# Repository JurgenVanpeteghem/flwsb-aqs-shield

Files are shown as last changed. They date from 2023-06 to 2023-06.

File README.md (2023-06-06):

# Air quality sensor shield
Flexible LoRaWAN Sensor Board - Air quality sensors shield

# Schematic
The schematic for the sensor shield was made using the reference schematics from the datasheets of the sensors. By adding female headers we can connect the main board to the sensorboard by using a male-female shield system. 
Four mounting holes were added to mount the board in an enclosure.

Connectorboard Figuur 1: Connectorboard

# PCB
For the project we made a seperate sensorboard wich contains all the sensors we used for the project. The purpose of this connector board is to connect all sensors to the main FLWSB. The FLWSB can collect the data drom the sensors on this board and send this data over lorawan.

The board contains following sensors to measure differnent parameters of airquality: 
  - BME280 (relative humidity and temperature 3,3V - I2C)
  - SGP41 (VOC and NOx sensor 3,3V - I2C)
  - SCD41 (CO2 sensor 3,3V - I2C)
  - JST-connector for SPS30 (particulate matter sensor 5V - I2C)

Additionally some pinheaders where added to connect a GY-NEO6MV2 GPS module and a solar power manager board to provide solar power to the board.

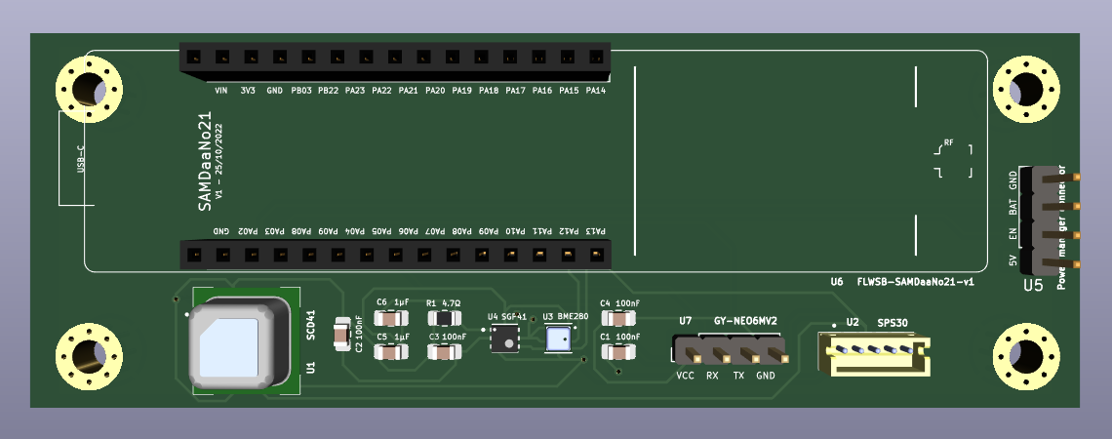
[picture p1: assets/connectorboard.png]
Connectorboard Figuur 2: Connectorboard


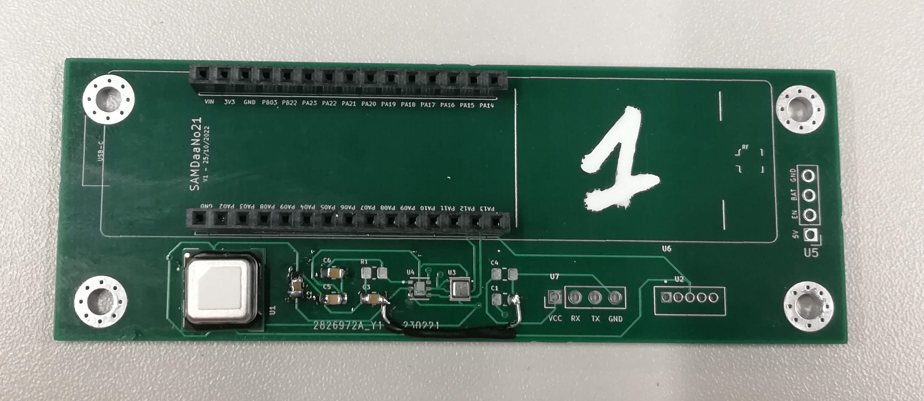
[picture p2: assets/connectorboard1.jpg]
Connectorboard Figuur 3: Connectorboard1


To solder the SMD sensors to the board solder paste was applied to the pads on the PCB. Then the sensors were soldered with a reflow oven. Soldering the small SMD sensors was a tricky part. To get the sensors to work, we had to try more than once with several boards.
At first we tried to solder the sensors with solder paste and hot air. This wasn't easy and with only the hot air we were not able to solder the sensors properly to the board.

A little wire had to be added to the board to correct a mistake made in the PCB design. Without the wire only the SCD41 and the SPS30 sensors would work. When the wire was added the other sensor work as well.

The mistake has already been corrected in the PCB design.

# Bill of materials
| Component  | amount  |
|---|---|
| 15 pin header female | 2 |
| 4 pin header male | 2 |
| SPS30 JST 5 pin connector | 1 |
| SDC41 | 1 |
| SGP41 | 1 |
| BME280 | 1 |
| capacitor 1µF  | 2  |
| capacitor 100nF  | 4  |
| resistor 4,7Ω  | 1  |

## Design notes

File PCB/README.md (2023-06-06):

# Air quality sensor shield

# PCB
For the project we made a seperate sensorboard wich contains all the sensors we use for the projetc. The purpose of this connector board is to connect all sensors to the main FLWSB. The FLWSB can collect the data drom the sensors on this board and send this data over lorawan.

The board contains following sensors to measure differnent parameters of airquality: 
  - BME280 (relative humidity- and tamperature 3,3V - I2C)
  - SGP41 (VOC en NOx sensor 3,3V - I2C)
  - SCD41 (CO2 sensor 3,3V - I2C)
  - Jst-connector for SPS30 (particulate matter sensor 5V - I2C)

additionally some pinheaders where added to connect a GY-NEO6MV2 GPS module and a solar power manager board to provide solar power to the board.

Connectorboard Figuur 1: Connectorboard

Connectorboard Figuur 2: Connectorboard1

To solder the SMD sensors to the board solder paste was applied to the pads on the PCB. Then we soldered the sensors with a reflow oven. To get the sensors to work, we had to put some boards a second time in the reflow oven.

# Bill of materials
| Component  | amount  |
|---|---|
| 15 pin header female | 2 |
| 4 pin header male | 2 |
| SPS30 JST 5 pin connector | 1 |
| SDC41 | 1 |
| SGP41 | 1 |
| BME280 | 1 |
| capacitor 1µF  | 2  |
| capacitor 100nF  | 4  |
| resistor 4,7Ω  | 1  |

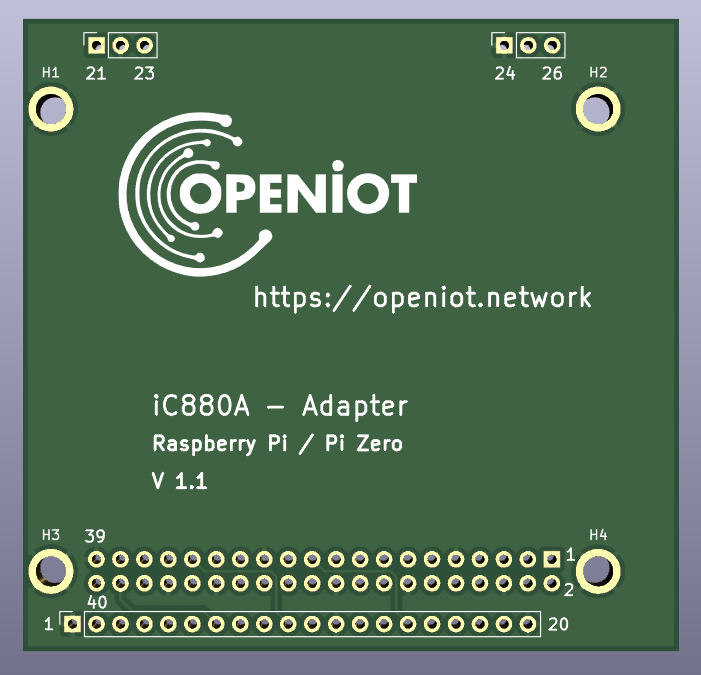
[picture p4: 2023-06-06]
assets/ic880A-adapter-board.png

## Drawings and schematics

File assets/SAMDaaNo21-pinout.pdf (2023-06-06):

# SAMDaaNo21

# A SAMD21 Developmentboard withLoRaWAN

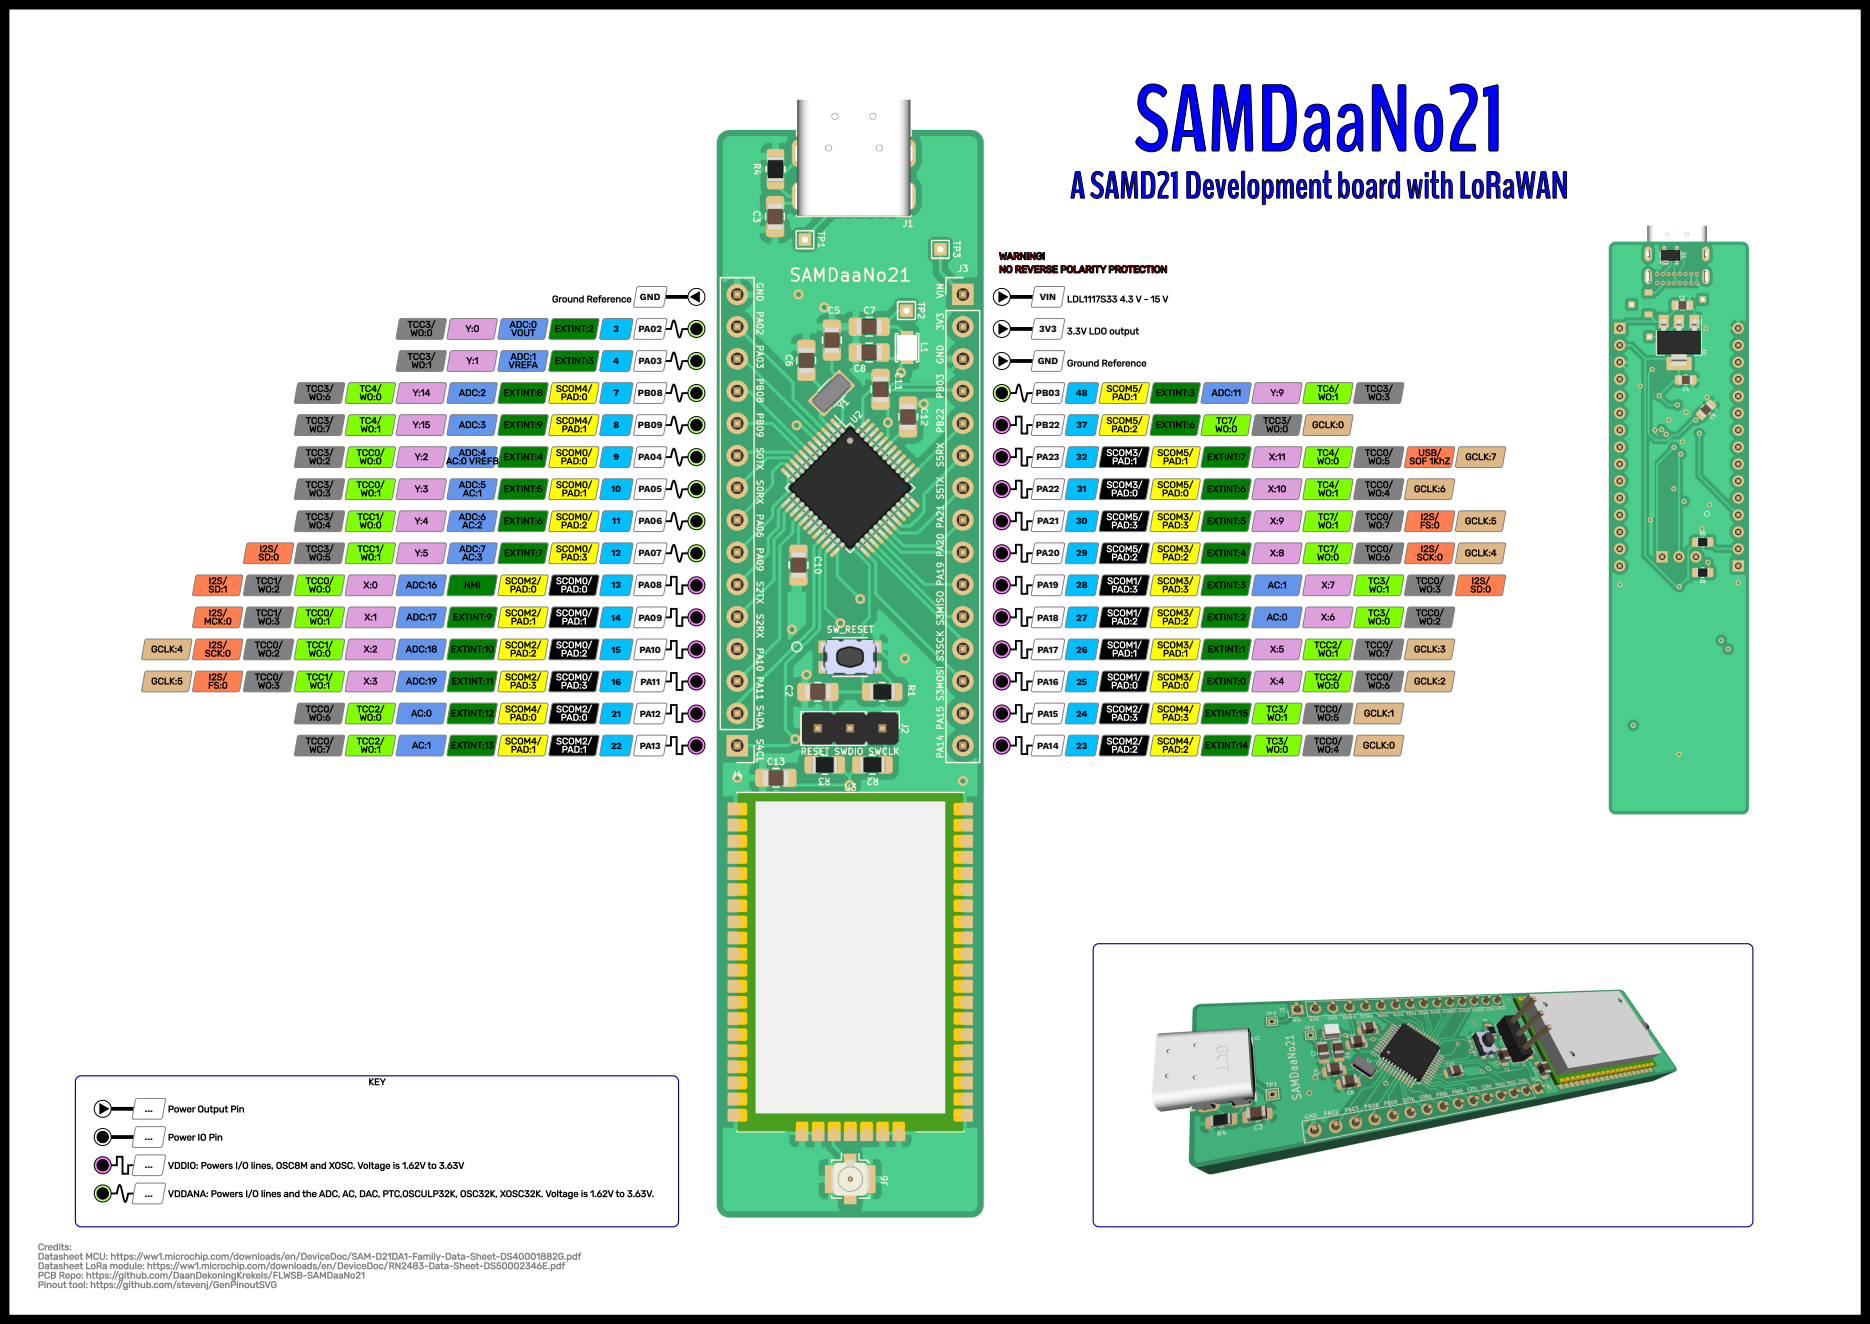
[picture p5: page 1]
EXTINT:2; PA02 ADC:0; VOUT; TCC3/ WO:0; EXTINT:3; PA03 ADC:1; VREFA; TCC3/ WO:1; SCOM4/ PAD:0; ADC:2; EXTINT:8; TCC3/ WO:6; SCOM4/ PAD:1; ADC:3; EXTINT:9; TCC3/ WO:7; SCOM0/ PAD:0; EXTINT:4 ADC:4 AC:0 VREFB; TCC0/ WO:0; TCC3/ WO:2; SCOM0/ PAD:1; EXTINT:5 ADC:5 AC:1; TCC0/ WO:1; TCC3/ WO:3; SCOM0/ PAD:2; EXTINT:6 ADC:6 AC:2; TCC1/ WO:0; TCC3/ WO:4; SCOM0/ PAD:3; EXTINT:7 ADC:7 AC:3; TCC1/ WO:1; TCC3/ WO:5; SCOM2/ PAD:0; ADC:16; NMI; TCC1/ WO:2; SCOM2/ PAD:1; ADC:17; TCC1/ WO:3; I2S/ MCK:0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

WARNING!
NO REVERSE POLARITY PROTECTION

Ground Reference GND

GND Ground Reference

Credits:
Datasheet MCU: https://ww1.microchip.com/downloads/en/DeviceDoc/SAM-D21DA1-Family-Data-Sheet-DS40001882G.pdf
Datasheet LoRa module: https://ww1.microchip.com/downloads/en/DeviceDoc/RN2483-Data-Sheet-DS50002346E.pdf
PCB Repo: https://github.com/DaanDekoningKrekels/FLWSB-SAMDaaNo21
Pinout tool: https://github.com/stevenj/GenPinoutSVG

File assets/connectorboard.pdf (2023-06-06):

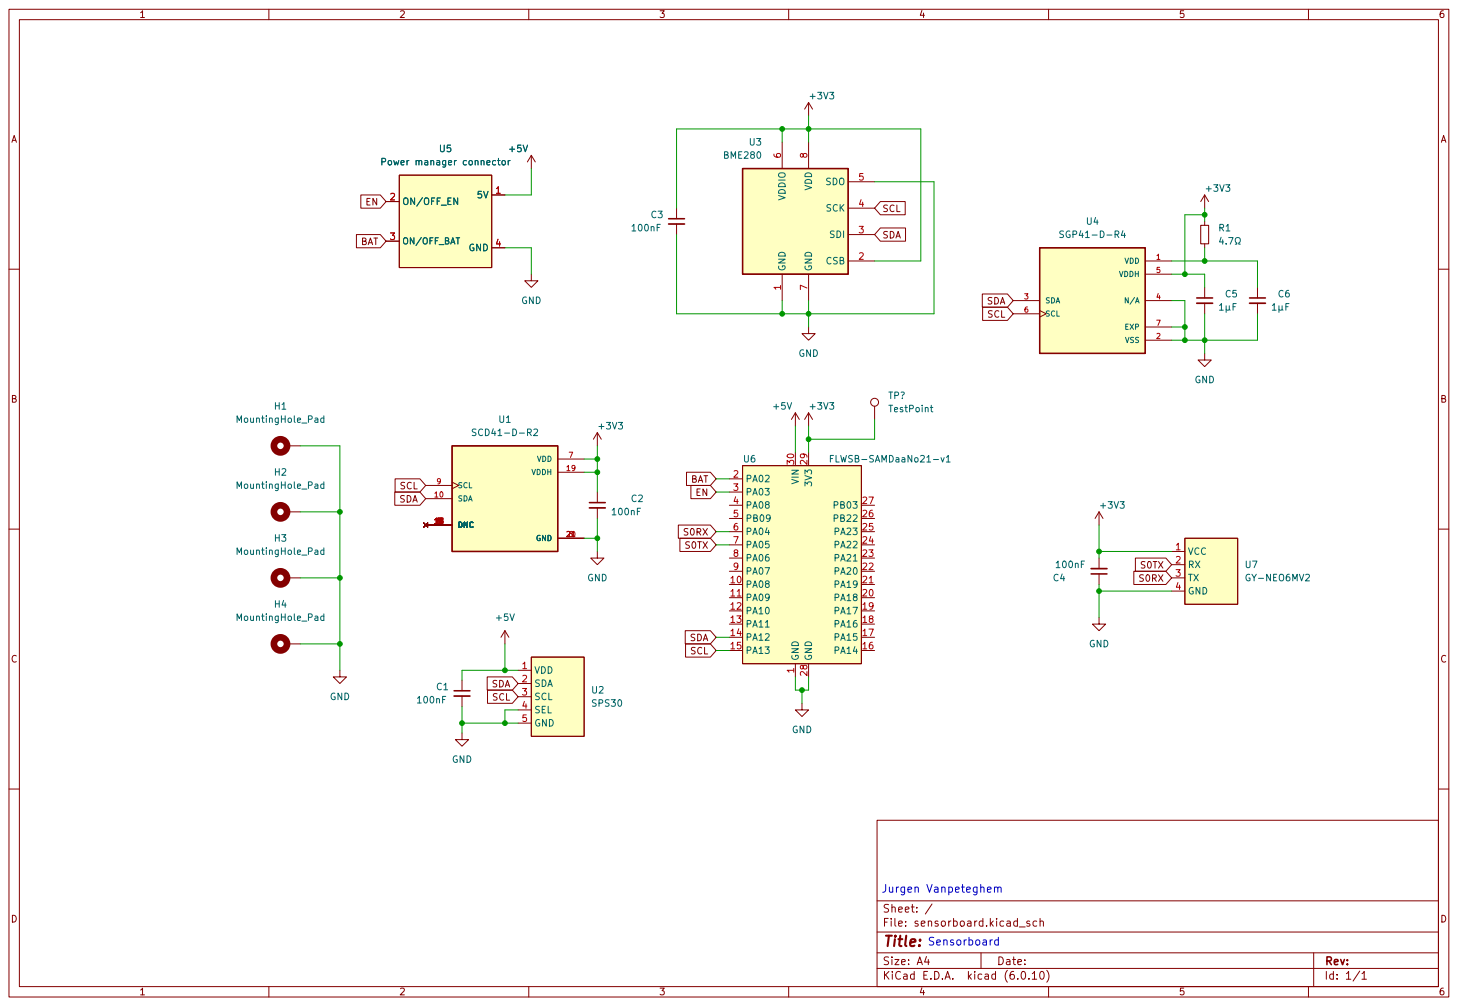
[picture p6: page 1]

1 CSB 2 SDI 3 SCK 4 SDO 5 VDDIO

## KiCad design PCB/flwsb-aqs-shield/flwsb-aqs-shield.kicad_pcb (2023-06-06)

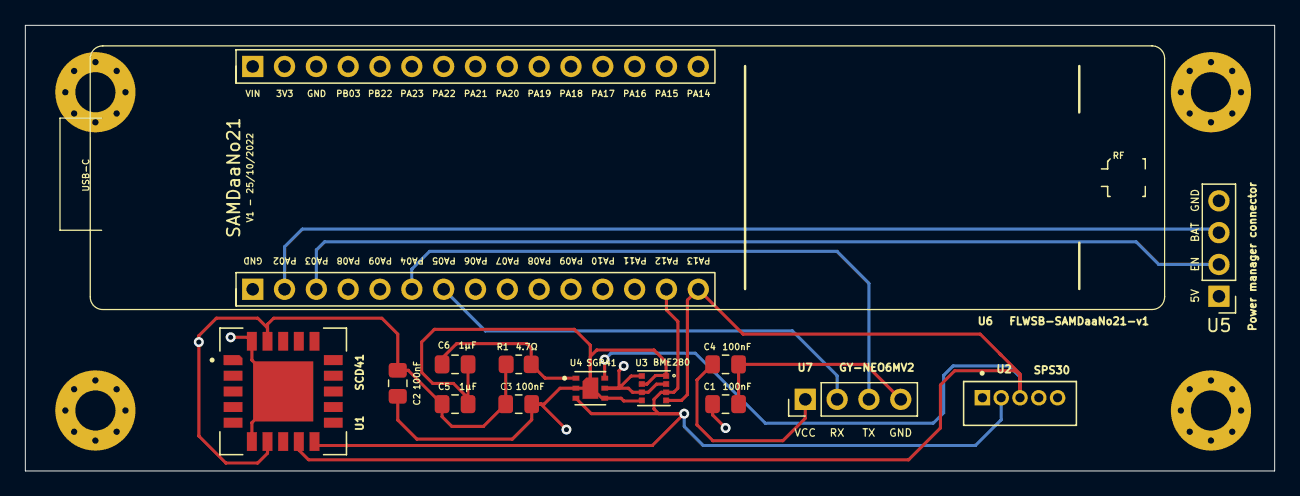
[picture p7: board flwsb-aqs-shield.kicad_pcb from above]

Board: 4 copper layers, 99.7 x 35.6 mm, 18 parts (0 on the bottom side), 10 nets.

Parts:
C1, C2, C3, C4: 100nF; C_0805_2012Metric_Pad1.18x1.45mm_HandSolder
C5, C6: 1µF; C_0805_2012Metric_Pad1.18x1.45mm_HandSolder
H1, H2, H3, H4: MountingHole_Pad; MountingHole_3.2mm_M3_Pad_Via
R1: 4.7Ω; R_0805_2012Metric_Pad1.20x1.40mm_HandSolder
U1: SCD41
U2: SPS30; JST_B5B-ZR(LF)(SN)
U3: BME280
U4: SGP41
U5: Power manager connector; PinHeader_1x04_P2.54mm_Vertical
U6: FLWSB-SAMDaaNo21-v1
U7: GY-NEO6MV2; PinHeader_1x04_P2.54mm_Vertical

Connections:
+3V3: C2.1, C3.1, C4.2, C5.1, R1.1, U1.7 (VDD), U1.19 (VDDH), U3.2 (CSB), U3.6 (VDDIO), U3.8 (VDD), U4.5 (VDDH), U6.29 (3V3), U7.1 (VCC)
+5V: C1.1, U2.1 (VDD), U5.1 (5V), U6.30 (VIN)
BAT: U5.3 (ON/OFF_BAT), U6.2 (PA02)
EN: U5.2 (ON/OFF_EN), U6.3 (PA03)
GND: C1.2, C2.2, C3.2, C4.1, C5.2, C6.2, H1.1, H2.1, H3.1, H4.1, U1.6 (GND), U1.20 (GND), U1.21 (GND), U2.4 (SEL), U2.5 (GND), U3.1 (GND), U3.5 (SDO), U3.7 (GND), U4.2 (VSS), U4.4 (N/A), U4.7 (EXP), U5.4 (GND), U6.1 (GND), U6.28 (GND), U7.4 (GND)
unnamed: C6.1, R1.2, U4.1 (VDD)
S0RX: U6.6 (PA04), U7.3 (TX)
S0TX: U6.7 (PA05), U7.2 (RX)
SCL: U1.9 (SCL), U2.3 (SCL), U3.4 (SCK), U4.6 (SCL), U6.15 (PA13)
SDA: U1.10 (SDA), U2.2 (SDA), U3.3 (SDI), U4.3 (SDA), U6.14 (PA12)
